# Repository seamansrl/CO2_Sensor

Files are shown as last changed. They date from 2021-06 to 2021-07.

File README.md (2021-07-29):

# Controla la calidad del aire de tu casa u oficina
Un sensor de CO2 es un instrumento que se utiliza para la medición de gas de dióxido de carbono en un ambiente determinado. Habitualmente estos aparatos registran el dióxido de carbono en partes por millón (ppm) en los espacios ocupados y nos ofrecen una muestra de la concentración de este gas en el aire que respiramos.

Este tipo de mediciones se han convertido en un elemento imprescindible en un entorno como el actual. Nuestras edificaciones son cada día más herméticas y, en consecuencia, mejor aisladas. La ventilación y concretamente la calidad del aire interior son aspectos primordiales relacionados con la salud y el confort de nuestras viviendas y espacios de trabajo sobre todo en esta epoca en donde nos vemos recluidos devido al COVID-19

Con la utilización de sensores de CO2 se pueden identificar las zonas o estancias habitadas en las que los niveles de dióxido de carbono son superiores a los aceptables. A partir de aquí habrá que diseñar o ajustar los sistemas de ventilación y el flujo de aire a estas necesidades con el fin de obtener la adecuada renovación y calidad del aire interior.

# Concentraciones habituales de CO2 y sus efectos
Como ya hemos comentado, las concentraciones de CO2 se miden en partes por millón (ppm). Dado que un elevado nivel de CO2 en el ambiente puede provocar efectos en la salud o en el rendimiento laboral, será aconsejable conocer los niveles considerados aceptables.

# Niveles válidos de concentración de CO2
Con relación a las concentraciones de CO2 los valores establecidos como válidos serían los siguientes:

- Concentraciones típicas de CO2 en ambientes exteriores: 350 – 450 ppm
- Concentraciones aceptables de CO2 en IAQ: 600 – 800 ppm
- Concentraciones tolerables de CO2 en IAQ: 1000 ppm

# Niveles de concentración de CO2 y sus efectos
Y en cuanto a los distintos niveles de concentración de CO2 (en ppm) y sus efectos sobre las personas se establecen los siguientes parámetros:

- Hasta 350 ppm; aire exterior
- Hasta 1.000 ppm; sensación de aire enrarecido
- Hasta 4.000 ppm; habitación mal ventilada
- Hasta 5.000 ppm; concentración máxima aconsejable en el lugar de trabajo.
- En concentraciones cercanas a los 30.000 ppm puede causar dolores de cabeza, falta de concentración, somnolencia, mareos y problemas respiratorios.

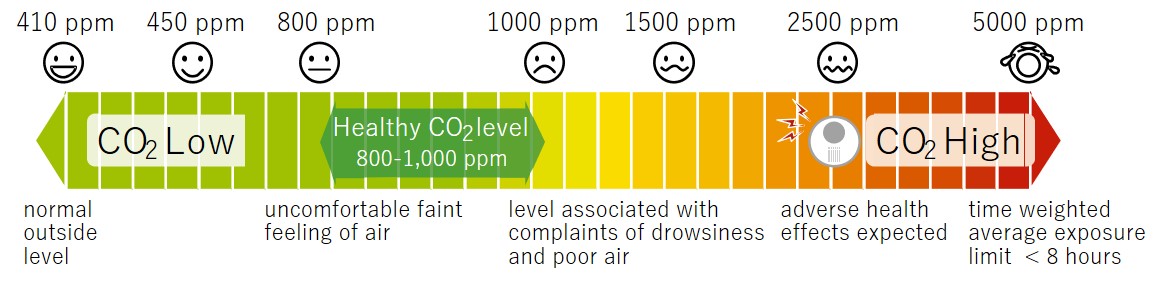
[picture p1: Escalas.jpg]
Escala


# Por que decimos que sirve para controlar el contagio de COVID-19
En la atmósfera, o sea, al aire libre, hay entre 350 y 450 partículas de CO2 por cada millón de partículas, eso significa que si estamos en un ambiente cerrado todo lo que esté por arriba de esos números está proveniendo de una fuente local. Asumimos que no estamos en un incendio ni trabajando con tubos de CO2 comprimidos o cualquier otra fuente, y por tanto lo único que quedaría que pueden generar CO2 son los seres vivos: humanos, animales, y plantas por la noche, pero excepto que vivas en un vivero es algo bastante despreciable.

O sea que en horarios diurnos si nuestro ambiente tiene 800 partículas por millón es asumible pensar que al menos un promedio de 400 de ellas fueron exhaladas por otro ser vivo. Si en el ambiente solo hay humanos, serían exhalados por otro humano. O sea que 400 de cada 1000000 de partículas el 0,4% del aire respirado fue exhalado previamente por nosotros mismos o alguien más.

El COVID-19 cae rápidamente al piso, por ello el usar tapabocas y mantener distancia es una forma relativamente buena de evitar el contagio, de estar en presencia de un enfermo de dicha patología (enfermo que podría ser asintomático). Aún así parte del spray exhalado aún queda en el aire, aquellas partículas más chicas y con menor masa, por tanto sin medimos el CO2 podemos tener una idea del grado de probabilidad de contagio al que nos sometemos al estar en el mismo ambiente cerrado con una persona contagiada que se encuentre a 2 metros de distancia y con tapabocas.

En resumen: si cumplimos con el distanciamiento social y el uso de mascarilla en un ambiente cerrado con 600 partículas por millón de CO2, tendremos un 0.4% de probabilidad de contagio, obviamente esa probabilidad aumenta con la distancia entre personas, el no uso de mascarilla y un ambiente con más de 2000 ppm de CO2, no es solución definitiva pero sin un elemento más de control, el cual es muy bueno en épocas de frío en donde tener todo el día la ventana abierta puede ser más problema que solucion.

# Elementos requeridos:
- 1x Arduino nano
- 1x Sensor MQ-135
- 1x DTH11
- Beeper activo
- Display de dos lineas con adaptador a I2C
- Cables

# Escquema:

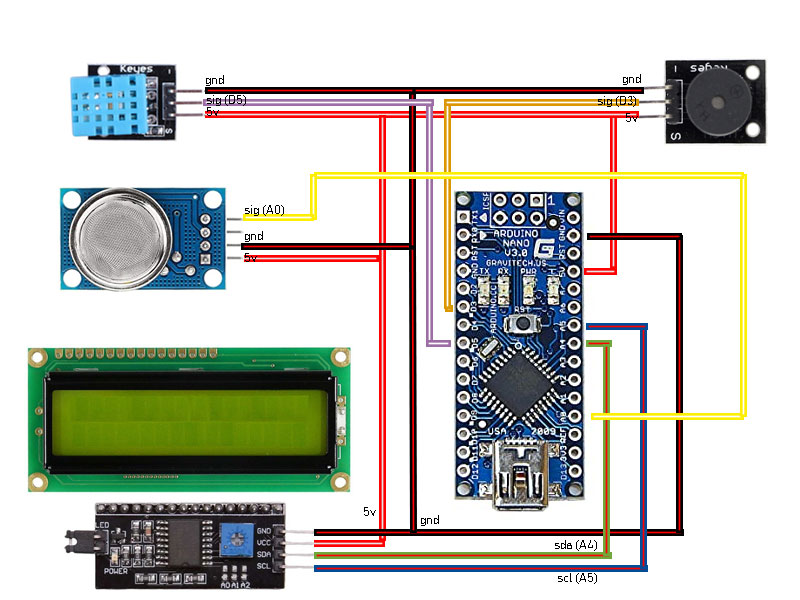
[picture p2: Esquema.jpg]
Esquema


# Pasos previos:
Antes de empezar deberemos instalar las librerías ubicadas en la carpeta “Librerias” en nuestro entorno Arduino.
Por lo demás solo es conectar, cargar el código y disfrutar.

# Calibración:
El sensor MQ135 es muy basico, solo consiste en una resistencia que varía segun la cantidad de CO2 con la que se la exita, esto implica 2 puntos a tener en cuenta:
1) La resistencia 102 ubicada del lado de atras arriba (lado contrario a los pines de conexion) entre medio de un capacitor y una resistencia es de 1K, algo inconveniente para usar con una arduino, lo que no implica que no sirva, solo que podria hacer a nuestras lecturas algo erraticas por lo que se recomienda cambiar por una resistencia de 10K o de 22K. Hecho esto deberemos ir al archivo MQ135.h y cambiar el valor de RLOAD de 1.0 a 10.0 o 22.0 segun la resistencia que pongamos en remplazo.
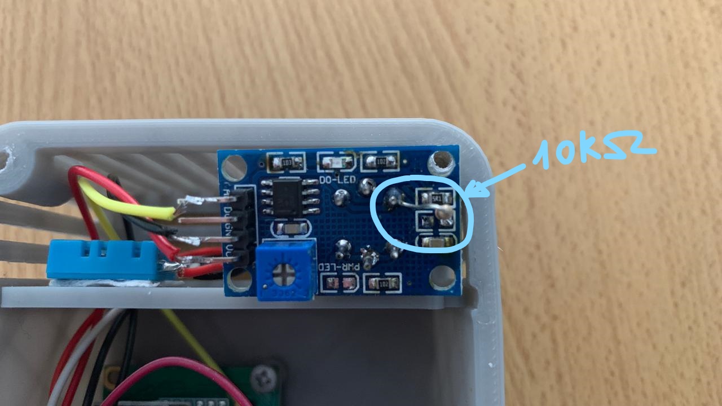
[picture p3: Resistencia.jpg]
Resistencia

2) Segun partida de sensores o marca es probable que varie el valor de la resistenciua interna del sensor, la llamada en el archivo MQ135.h como RZERO, algo que deberemos calibrar para tener mediciones correctas. Para ello nos llevaremos el equipo terminado al exterior (Balcon o terraza) y con el terminal abierto nos quedaremos viendo por al menos 10 a 15 minutos que el valor que se imprime en pantalla se estabilice en un numero. Ese numero es el que remplazaremos en RZero.

Compilamos y cargamos en la arduino nuevamente con los valores detectados y si esta todo OK deberemos medir de 390ppm a 490ppm valores "normales" para una medicion al aire libre. 

# Update 29-07-2021:
Se implemento un modo de auto ajuste del RZero. Esto no implica que no se deba calibrar, pero si por alguna razon el valor registrado de CO2 en un ambiente cerrado y con el equipo bien calibrado da por debajo del nivel minimo de contamincion en la armosfera o sea la variable ATMOCO2, asumimos que la resistencia del sensor no tiene temperatura suficiente y esta midiendo mal por lo cual reasignamos el valor de RZero al valor medido. 
En definitiva, si el nivel de CO2 medido es menor al indicado que deberia haber en la atmosfera al aire libre o sea la variable ATMOCO2, se reajusta la variable RZero al valor en curso para que la medicion tome como nueva cota minima dicho valor.

# Contactanos en:
https://www.linkedin.com/company/35599193/admin/

# Seguime en:
https://www.linkedin.com/in/fernando-p-maniglia/

# Conocenos más en:
https://www.seamansrl.com.ar

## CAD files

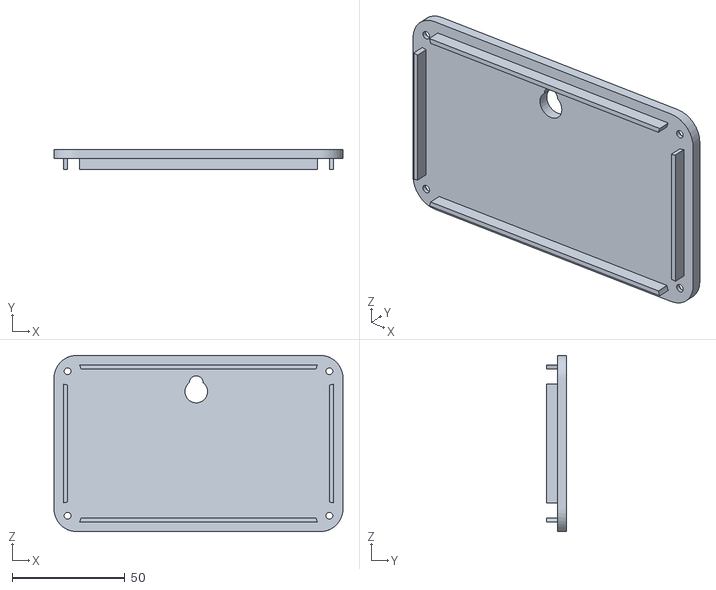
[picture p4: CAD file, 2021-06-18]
Carcasa/lid.stl
128.0 x 9.00 x 78.0

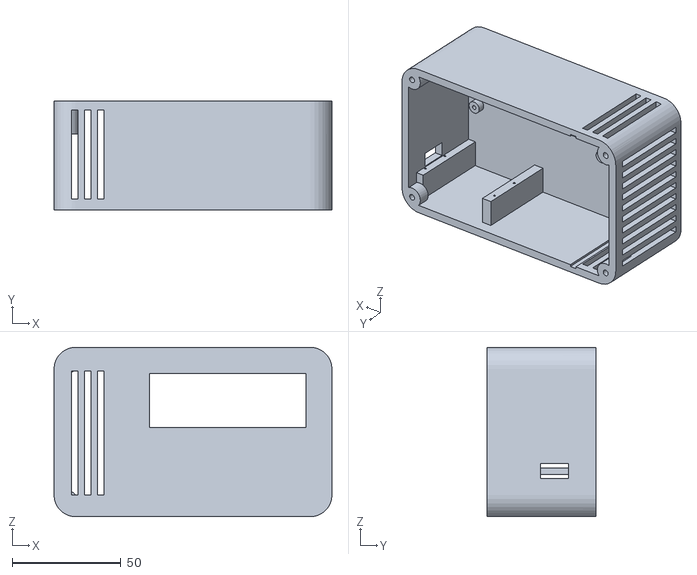
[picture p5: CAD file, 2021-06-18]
Carcasa/box_nano.stl
128.0 x 50.0 x 78.0

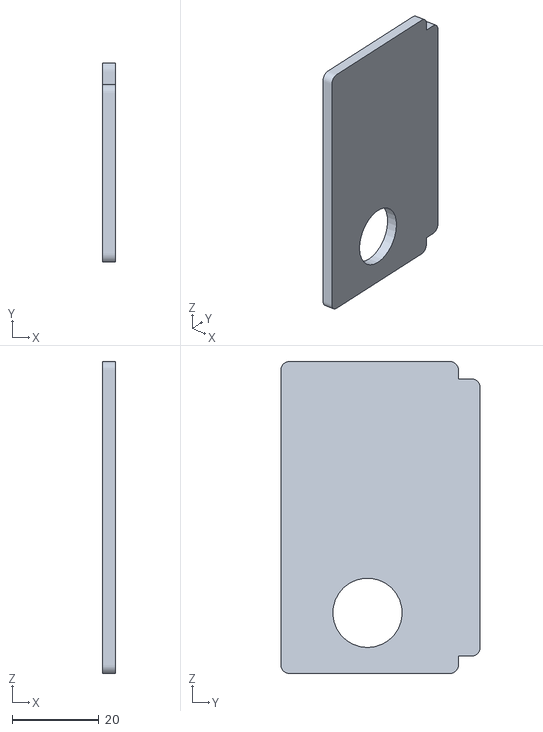
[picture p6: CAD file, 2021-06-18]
Carcasa/wall.stl
3.00 x 46.0 x 72.0

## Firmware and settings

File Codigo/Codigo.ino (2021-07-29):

// PROYECTO DESARROLLADO POR SEAMAN SRL
// EL PRESENTE CODIGO SE ENTREGA SIN GARANTIA ALGUNA
// A REVISAR: SI BIEN LOS CALCULOS SE REALIZAN USANDO LA TABLA DE ESPECIFICACION DEL MQ135 ESTOS NO FUERON VERIFICADOS CON RIGUROSIDAD
// Y PODRIAN REQUERIR AJUSTES ADICIONALES EN LAS LIBRERIAS MQ135.H

#include "DHT.h"
#include "MQ135.h"
#include <LiquidCrystal_I2C.h>

// DECLARO PANTALLA DE DOS LINEAS
LiquidCrystal_I2C lcd(0x27, 2, 1, 0, 4, 5, 6, 7, 3, POSITIVE);

// DEFINO TIPO DE SENSOR DE TEMPERATURA Y HUMEDAD
#define DHTTYPE DHT11
// #define DHTTYPE DHT22 // ES UN SENSOR MUCHO MEJOR

// DEFINO EL PIN DONDE SE CONECTARA EL SENSOR MQ135
#define MQ135_PIN 0

// DEFINO EL PIN DONDE SE CONECTARA EL SENSOR DHT11
#define DHT_PIN 5

// DEFINO EL PIN DONDE SE CONECTARA EL BEEPER ACTIVO
#define BEEPER_PIN 3

// DEFINO UN OFFSET PARA EL SENSOR DHT11, O SEA, HAY QUE MODIFICARLO PARA AJUSTAR LO MEDIDO EN EL PRESENTE PROYECTO CON LO MEDIDO EN UN RERMOMETRO PATRON
#define DHT_OFFSET -4

// PARAMETRIZO SENSOR DHT
DHT dht(DHT_PIN, DHTTYPE);

// DECLARO EL MQ-135
MQ135 MQ135_SENSOR = MQ135(MQ135_PIN);

// DECLARO LAS VARIABLES DE QUE SE USARAN PARA MEDIR 
float humedad = 0;
float temperatura = 0;
float CO2_PPM = 0; 

// VARIABLES QUE MIDE EL TIEMPO ENTRE CADA BEEP SEGUN NIVEL DE CONCENTRACIÓN DE CO2
unsigned long startMillis;
unsigned long currentMillis;
unsigned long elapsedMillis;

// VARIABLES QUE MIDE EL TIEMPO ENTRE CADA BEEP SEGUN NIVEL DE CONCENTRACIÓN DE CO2
unsigned long ReadStartMillis;
unsigned long ReadCurrentMillis;
unsigned long ReadElapsedMillis;

// SIMBOLO DE GRADOS

byte CaraMuyFeliz[] = {
  B00000,
  B00000,
  B01010,
  B00000,
  B11111,
  B10001,
  B01110,
  B00000
};

byte CaraFeliz[] = {
  B00000,
  B00000,
  B01010,
  B00000,
  B10001,
  B01110,
  B00000,
  B00000
};

byte CaraNeutral[] = {
  B00000,
  B00000,
  B01010,
  B00000,
  B00000,
  B11111,
  B00000,
  B00000
};

byte CaraTriste[] = {
  B00000,
  B00000,
  B01010,
  B00000,
  B01110,
  B10001,
  B00000,
  B00000
};

byte CaraMuyTriste[] = {
  B00000,
  B00000,
  B01010,
  B00000,
  B00000,
  B10101,
  B01010,
  B00000
};

byte CaraGritando[] = {
  B00000,
  B01010,
  B00000,
  B00100,
  B01010,
  B10001,
  B01010,
  B00100
};

byte Gota[] = {
  B00000,
  B00100,
  B01110,
  B11111,
  B11111,
  B11111,
  B01110,
  B00000
};

byte Termometro[] = {
  B00100,
  B01010,
  B01010,
  B01010,
  B01110,
  B11111,
  B11111,
  B01110
};

byte Aire[] = {
  B00000,
  B00000,
  B01000,
  B10101,
  B00010,
  B01000,
  B10101,
  B00010
};

// FUNCION PARA HACER SONAR EL BEEPER ACTIVO
void beep()
{
    digitalWrite(BEEPER_PIN, LOW);
    delay(100); 
    digitalWrite(BEEPER_PIN, HIGH);
    delay(100); 
    digitalWrite(BEEPER_PIN, LOW);
    delay(100); 
    digitalWrite(BEEPER_PIN, HIGH);  
}

// INICIALIZO EL SCRIPT
void setup() {
  Serial.begin(57600);
  
  lcd.begin(16, 2);
  lcd.backlight();

  dht.begin();
  
  pinMode(3, OUTPUT);
  digitalWrite(3, HIGH);

  // CREO CARACTERES ESPECIALES
  lcd.createChar(1, CaraMuyFeliz);
  lcd.createChar(2, CaraFeliz);
  lcd.createChar(3, CaraNeutral);
  lcd.createChar(4, CaraTriste);
  lcd.createChar(5, CaraMuyTriste);
  lcd.createChar(6, CaraGritando);
  lcd.createChar(7, Gota);
  lcd.createChar(8, Termometro);
  lcd.createChar(9, Aire);
  
  // EL SENSOR DEBE CALENTAR PARA REALIZAR MEDICIONES CORRECTAR POR LO CUAL LE DOY 30 SEGUNDOS DE TIEMPO PARA DICHA TAREA
  lcd.home();
  lcd.print("Iniciando...");
  
  for (int porcentual = 0; porcentual <= 100; porcentual++)
  {
    lcd.setCursor(0, 1);
    lcd.print(String(porcentual) + "%");
    delay(300);
  }
  
  lcd.clear();
}

void loop() {
  // LOS CICLOS DE REFRESCO SON CADA 1 SEGUNDOS
  delay(10);

  ReadCurrentMillis = millis();
  ReadElapsedMillis = ReadCurrentMillis - ReadStartMillis;

  // LEO LOS SENSORES CADA 5 SEGUNDOS
  
  if (ReadElapsedMillis >= 5000)
  {
    ReadStartMillis = millis();

    if (DHTTYPE == DHT11)
    {
      // EL DHT11 ES UNA BASURA ASI QUE HACEMOS ALGUNAS MAGIAS COMO PARA QUE LA HUMEDAD ESTE MAS CERCA DE LA REALIDAD
      humedad = dht.readHumidity();
      humedad = (100/ 40 * humedad) - 25;

      if (humedad > 100)
        humedad = 100;
    }
    else
    {
      humedad = dht.readHumidity();
    }

    humedad = dht.readHumidity();
    temperatura = dht.readTemperature() + DHT_OFFSET;

    // DEPENDE DEL SENSOR LA ESCALA PUEDE QUE SE REQUIERA AJUSTAR ASI QUE.... BUENO, ESO...
    // MULTIPLICO DE A 10 HASTA QUE LA MEDICION DE MAYOR A 100 YA QUE NUNCA HAY MENOS DE 100 PPM
    // EN LA ATMOSFERA... MAL POR LOS HUMANOS PERO ES ASI.
    
    for (int Escala=1; Escala <=10000; Escala = Escala * 10)
    {
        CO2_PPM = MQ135_SENSOR.getCorrectedPPM(temperatura, humedad) * Escala; 

        if (CO2_PPM > 100)
          break;
    }

    // IMPRIMO EL RZERO AJUSTADO
    Serial.print(MQ135_SENSOR.SetedRZero());
    Serial.print("|");
    
    // IMPRIMO LA RZERO DE MEDIDO
    Serial.print(MQ135_SENSOR.getRZero());
    Serial.print("|");

    // IMPRIMO LA TEMPERATURA EN CASO QUE SE QUIERA USAR EL EQUIPO CONECTADO A UNA PC PARA HACER LOGIN
    Serial.print(temperatura);
    Serial.print("|");

    // IMPRIMO LA HUMEDAD EN CASO QUE SE QUIERA USAR EL EQUIPO CONECTADO A UNA PC PARA HACER LOGIN
    Serial.print(humedad);
    Serial.print("|");

    // IMPRIMO EL CO2 EN CASO QUE SE QUIERA USAR EL EQUIPO CONECTADO A UNA PC PARA HACER LOGIN
    Serial.print(CO2_PPM);
    Serial.println();
    
    char str[3];
   
    // PRESENTO LA INFORMACION EN PANTALLA
    // ICONO DE AIRE
    lcd.setCursor(0, 0);
    lcd.write(9);
  
    lcd.setCursor(1, 0);
    lcd.print("              ");
    lcd.setCursor(1, 0);
    lcd.print(String(CO2_PPM) + " ppm");
  
    // ICONO DE GOTA
    lcd.setCursor(0, 1);
    lcd.write(7);
    
    lcd.setCursor(1, 1);
    lcd.print(String(dtostrf(humedad, 2, 1, str)) + "%");
  
    // ICONO TERMOMETRO
    lcd.setCursor(7, 1);
    lcd.write(8);
  
    lcd.setCursor(8, 1);
    lcd.print(String(dtostrf(temperatura, 2, 1, str)) +  "\337c");
  }


  // ------------------------------------------------------------------------------------
  // AUTOCALIBRACION OPCIONAL. ASUMIMOS QUE SI LA ATMOSFERA TIENE AL MENOS LO REGISTRADO EN ATMOCO2 COMO PPM DE CO2, TODO VALOR POR DEBAJO ESTARA MAL
  // ASI QUE LO QUE HACEMOS ES REAJUSTAR EL RZERO AL NUEVO VALOR, PERO LO HACEMOS DE FORMA VOLATIL DE FORMA QUE SI ESA BAJO VALOR ES REAL SE PUEDA RESETEAR
  if (CO2_PPM < MQ135_SENSOR.GetAtmos())
  {
    MQ135_SENSOR.SetRZero();

    return;
  }
  // ------------------------------------------------------------------------------------

  // HAGO SONAR UNA ALERTA SI LA CONSENTRACION DE CO2 SUPERRA LOS 800, AUMENTANDO LA FRECUENCIA DE PITIDOS SEGUN CONCENTRACIÓN
  currentMillis = millis();
  elapsedMillis = (currentMillis - startMillis);

  if (CO2_PPM > 5000)
  {
    if (elapsedMillis > 1000)
    {
      beep();
      startMillis = millis();
    }

    lcd.setCursor(15, 0);
    lcd.write(6);

    return;
  }
  
  if (CO2_PPM > 3000 && elapsedMillis > 2000)
  {
    if (elapsedMillis > 2000)
    {
      beep();
      startMillis = millis();
    }

    lcd.setCursor(15, 0);
    lcd.write(6);

    return;
  }
  
  if (CO2_PPM > 2500)
  {
    if (elapsedMillis > 5000)
    {
      beep();
      startMillis = millis();
    }

    lcd.setCursor(15, 0);
    lcd.write(6);

    return;
  }
  
  if (CO2_PPM > 2000)
  {
    if (elapsedMillis > 10000)
    {
      beep();
      startMillis = millis();
    }

    lcd.setCursor(15, 0);
    lcd.write(5);

    return;
  }
  
  if (CO2_PPM > 1500)
  {
    if (elapsedMillis > 15000)
    {
      beep();
      startMillis = millis();
    }

    lcd.setCursor(15, 0);
    lcd.write(4);

    return;
  }
  
  if (CO2_PPM > 1000)
  {
    if (elapsedMillis > 30000)
    {
      beep();
      startMillis = millis();
    }

    lcd.setCursor(15, 0);
    lcd.write(3);

    return;
  }
  
  if (CO2_PPM > 800)
  {
    if (elapsedMillis > 60000)
    {
      beep();
      startMillis = millis();
    }
    
    lcd.setCursor(15, 0);
    lcd.write(3);

    return;
  }

  if (CO2_PPM <= 450)
  {
    startMillis = millis();
    
    lcd.setCursor(15, 0);
    lcd.write(2);

    return;
  }
  
  if (CO2_PPM <= 800)
  {
    startMillis = millis();

    lcd.setCursor(15, 0);
    lcd.write(2);

    return;
  }
}

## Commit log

2021-06-21 Update Codigo.ino
    Actualización: Alertas variables en el tiempo según nivel de concentración de CO2.
2021-06-22 Update Codigo.ino
    Se modifico la forma en la que se muestran los datos
    Se arreglaron fallas menores
    Se incorpora iconos
    Se mejora el refresco de pantalla
    Se incorpora iconos de caritas indicando la calidad del aire
    [Codigo.ino]
2021-06-23 Update Codigo.ino
    Compatibilidad para sensor DHT22 y algunas magias negras para que el DHT11 no sea tan malo
2021-06-23 Update Codigo.ino
    Corrección en el dalay del beeper
2021-06-24 Update Codigo.ino
    Auto escalado según tipo de sensor
2021-06-25 Update MQ135.cpp
    Agregué algo más de comentarios para entender mejor como funciona
2021-06-25 Update Codigo.ino
    Imprimo el valor de RZERO para su calibracion
2021-06-26 Update Codigo.ino
    Se anexa un grupo de print seriales para usar en software de PC para LOG o interfaz grafica
